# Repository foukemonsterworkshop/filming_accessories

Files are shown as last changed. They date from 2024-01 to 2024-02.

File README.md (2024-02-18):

# DIY Filming Accessories

### The Boom
I became frustrated with the limitations of tripods in my small shop space and after a few sources of inspiration started working on a balanced arm boom.
The boom is mounted to a single point, but the mount can be reused or dovetailed into a duplicated mounting point.

Projects that I felt most influenced this camera arm:
Two from Marius Hornberger  
https://www.youtube.com/watch?v=7V0NvNZmvXU
https://youtu.be/p68Y1e4acF4?si=vS-Dpx9isLgJdFHX

This massive Gantry from Inheritance Machining  
https://www.youtube.com/watch?v=t1sXvMY_vAw

And a series from The Meandrous Engineer  
https://www.youtube.com/watch?v=fble2ifR0NI

A group of .3mf files and an export of the Fusion 360 (.f3d) have been included.

### The Dolly
Real dollys are expensive, and the ones that are "smart" are much _more_ expensive.
This one is made almost entirely of 3d printed parts, extremely cheap components, and wood.

I used a knockoff arduino mega, a knockoff ILI9341 touchscreen, and some small and inexpensive stepper motors.

The necessary arduino files are {here}
And the models can be found {here}

Wiki information for the specific touch screen I used can be found  
http://www.lcdwiki.com/3.2inch_SPI_Module_ILI9341_SKU:MSP3218

I originally started with much too weak Stepper motors.  
https://www.amazon.com/gp/product/B07YRHX73L/ref=ppx_yo_dt_b_search_asin_title?ie=UTF8&psc=1

And a related tutorial I used is here:  
https://lastminuteengineers.com/28byj48-stepper-motor-arduino-tutorial/

After the initial test and finding that they would not perform the required action, I switched to these nema 17 stepper motors.  
https://www.amazon.com/dp/B00PNEQKC0?psc=1&ref=ppx_yo2ov_dt_b_product_details  
https://www.amazon.com/dp/B00PNEQ79Q?psc=1&ref=ppx_yo2ov_dt_b_product_details

L298N motor drivers  
Testing with these motor drivers resulted in jittery movement and drop in power when controlled in tandem.  
They also got super hot.  
https://www.amazon.com/dp/B00NJOTBOK?psc=1&ref=ppx_yo2ov_dt_b_product_details

And these related tutorial from the same place  
https://lastminuteengineers.com/stepper-motor-l298n-arduino-tutorial/

TB6600 stepper drivers  
I moved on to a more familiar CNC style controller  
https://www.amazon.com/gp/product/B088CRCMP7/ref=ppx_yo_dt_b_asin_title_o00_s00?ie=UTF8&th=1

And used these tutorials:  
https://www.makerguides.com/tb6600-stepper-motor-driver-arduino-tutorial/

A group of .3mf files and an export of the Fusion 360 (.f3d) have been included.
In addition some of the sub-assembly projects have been included for further customation.

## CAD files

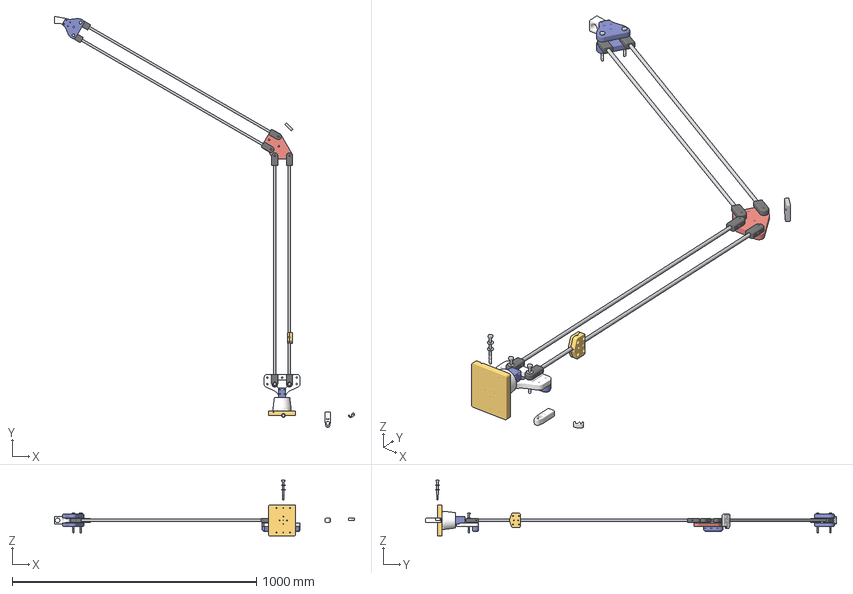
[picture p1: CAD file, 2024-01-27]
Boom3dFiles/Balanced Arm Boom v16.3mf
1229.1 x 1682.1 x 228.1 mm
Attachment Plate V2
Foot (1) x 4
Foot x 4
Link
Rod x 4
v2

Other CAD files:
Dolly3dFiles/Adjustable Phone Clamp v7.f3d
Dolly3dFiles/Parameterized Cable Chain v8.f3d

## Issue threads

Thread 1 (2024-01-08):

Navigate to Home from button

foukemonsterworkshop, 2024-01-08:
When creating a HomeButton, the NavigateTarget returns as a large number and not the intended enum

foukemonsterworkshop, 2024-01-10:
Fixed

Closed 2024-01-10.

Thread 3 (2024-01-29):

L298N Motor Driver imprecise for use case

foukemonsterworkshop, 2024-01-29:
L298N Driver should be replaced so models need to reflect this change and code will interact with the drivers differently

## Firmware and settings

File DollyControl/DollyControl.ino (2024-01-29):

#include <LCDWIKI_GUI.h>    //Core graphics library
#include <LCDWIKI_SPI.h>    //Hardware-specific library
#include <LCDWIKI_TOUCH.h>  //touch screen library

#include <Regexp.h>

#include "ScreenDefinitions.h"
#include "MenuEnums.h"

#include "StepperOperation.h"

//if the IC model is known or the modules is unreadable,you can use this constructed function
LCDWIKI_SPI lcd(MODEL, CS, CD, RST, LED);  //model,cs,dc,reset,led
LCDWIKI_TOUCH touch(TCS, TCLK, TDOUT, TDIN, TIRQ);

//navigation and interaction variables
int px, py;
boolean requires_redraw = false;

MenuState current_state;
MenuState prev_state;

STEPPER_FOCUS s_focus;
STEPPER_INPUT s_input;

String current_input = "";

//machine travel variables
boolean steppers_active = true;

// Defines the number of steps per rotation
const int stepsPerRevolution = 200;
// Creates an instance of stepper class
// Pins entered in sequence IN1-IN3-IN2-IN4 for proper step sequence

//g2t belt driven
//Belt pitch: 2mm
//No. Teeth in model pulley: 40
//mm per rotation = 80mm
Stepper gantry_stepper = Stepper(stepsPerRevolution, 2, 3, 4, 5);

//herringbone gear driven
//drive gear has 18 teeth
//camera stand gear has 36 teeth
//1 rotation = .5 camera rotation
Stepper pan_stepper = Stepper(stepsPerRevolution, 6, 7, 8, 9);

void setup(void) {
  Serial.begin(9600);
  Serial.println("");

  current_state = MAIN;
  requires_redraw = true;

  lcd.Init_LCD();
  lcd.Set_Rotation(2);
  touch.TP_Set_Rotation(3);
  touch.TP_Init(lcd.Get_Rotation(), lcd.Get_Display_Width(), lcd.Get_Display_Height());
  lcd.Fill_Screen(WHITE);

  gantry_stepper.setSpeed(60);

}

void loop(void) {

  if (requires_redraw) {
    lcd.Fill_Screen(WHITE);
    requires_redraw = false;

    init_menu(current_state);
  }

  px = 0;
  py = 0;
  touch.TP_Scan(0);
  if (touch.TP_Get_State() & TP_PRES_DOWN) {
    px = touch.x;
    py = touch.y;
  }

  interact_with_menu(current_state, px, py);

}

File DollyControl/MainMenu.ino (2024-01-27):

void init_main_menu() {
  int x = 5;
  int y = 5;
  int x1 = lcd.Get_Display_Width() - x;
  int y1 = 30;

  int list_position = 0;
  int display_position = 1;

  int labelXOffset = 2 * x;
  int labelYOffset = 12;

  String content = steppers_active ? "Motors Active" : "Motors Inactive";
  int label_size = 2;

  char* labels[6] = { " ", "Home Machine", "Jog Machine", "Pan Machine", "Truck Machine", "Parallax Machine" };

  for (int i = 0; i < 6; i++) {
    int16_t color;
    if (i == 0) {
      color = steppers_active ? GREEN : RED;
    } else {
      color = LIGHTGREY;
      content = labels[i];
    }

    lcd.Set_Draw_color(color);
    lcd.Fill_Round_Rectangle(
      x,
      (display_position * y) + (list_position * y1),
      x1,
      display_position * (y + y1),
      3);

    show_label(content, labelXOffset, labelYOffset + (i * (y1 + y)), label_size, BLACK, BLACK, 1);

    list_position++;
    display_position++;
  }
}

void interact_main_menu(int px, int py) {
  int x = 5;
  int y = 5;
  int x1 = lcd.Get_Display_Width() - x;
  int y1 = 30;

  int list_position = 0;
  int display_position = 1;

  int labelXOffset = 2 * x;
  int labelYOffset = 12;

  if (is_pressed(px, py,
                 x,
                 (display_position * y) + (list_position * y1),
                 x1,
                 display_position * (y + y1))) {
    steppers_active = !steppers_active;
    lcd.Set_Draw_color(steppers_active ? GREEN : RED);
    lcd.Fill_Round_Rectangle(
      x,
      (display_position * y) + (list_position * y1),
      x1,
      display_position * (y + y1),
      3);
    show_label(steppers_active ? "Motors Active" : "Motors Inactive", labelXOffset, labelYOffset, 2, BLACK, BLACK, 1);
    delay(1000);
  }

  list_position++;
  display_position++;

  MenuState state[6] = { MAIN, HOME, JOG, PAN, TRUCK, PARALLAX };

  for (int i = 1; i < 6; i++) {

    if (is_pressed(px, py,
                   x,
                   (display_position * y) + (list_position * y1),
                   x1,
                   display_position * (y + y1))) {
      button_reaction(
        DARKGREY,
        x,
        (display_position * y) + (list_position * y1),
        x1,
        display_position * (y + y1));

      requires_redraw = true;
      prev_state = current_state;
      current_state = state[i];
      delay(150);
    }

    list_position++;
    display_position++;
  }

}

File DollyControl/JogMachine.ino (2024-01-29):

void init_jog_menu() {
  int x = 5;
  int y = 5;
  int x1 = lcd.Get_Display_Width() - x;
  int y1 = 30;

  int list_position = 0;
  int display_position = 1;

  int labelXOffset = 2 * x;
  int labelYOffset = 12;

  lcd.Set_Draw_color(DARKGREY);
  lcd.Fill_Round_Rectangle(
    x,
    (display_position * y) + (list_position * y1),
    x1,
    display_position * (y + y1),
    3);
  show_label("Jog Machine", labelXOffset, labelYOffset, 2, BLACK, BLACK, 1);

  lcd.Set_Draw_color(GREEN);
  float jogX = lcd.Get_Width() / 4;
  float jogY = lcd.Get_Height() / 4;
  lcd.Fill_Circle(jogX, jogY, 25);

  String label_text = "Left";

  float label_size = 2.0;
  show_label(label_text,
             jogX - label_text.length() * label_size * 6 / 2 + label_size / 2 + 1,
             jogY - label_size * 8 / 2 + label_size / 2 + 1,
             label_size,
             BLACK, BLACK, 1);

  jogX = lcd.Get_Width() * (3.0 / 4.0);

  lcd.Fill_Circle(jogX, jogY, 25);

  label_text = "Right";

  show_label(label_text,
             jogX - label_text.length() * label_size * 6 / 2 + label_size / 2 + 1,
             jogY - label_size * 8 / 2 + label_size / 2 + 1,
             label_size,
             BLACK, BLACK, 1);

  jogY = lcd.Get_Height() / 2;
  jogX = lcd.Get_Width() / 4;

  lcd.Fill_Circle(jogX, jogY, 25);

  label_text = "P Left";

  show_label(label_text,
             jogX - label_text.length() * label_size * 6 / 2 + label_size / 2 + 1,
             jogY - label_size * 8 / 2 + label_size / 2 + 1,
             label_size,
             BLACK, BLACK, 1);

  jogX = lcd.Get_Width() * (3.0/ 4.0);

  lcd.Fill_Circle(jogX, jogY, 25);

  label_text = "P Right";

  show_label(label_text,
             jogX - label_text.length() * label_size * 6 / 2 + label_size / 2 + 1,
             jogY - label_size * 8 / 2 + label_size / 2 + 1,
             label_size,
             BLACK, BLACK, 1);

  draw_nav_button("Home");
}

void interact_jog_menu(int px, int py) {

  /*
    Serial.print("Jog Menu click-> x: ");
    Serial.print(px);
    Serial.print(" y: ");
    Serial.println(py);
  */

  float label_size = 2.0;

  check_home_button(px, py);

  float jogX = lcd.Get_Width() / 4;
  float jogY = lcd.Get_Height() / 4;

  gantry_stepper.setSpeed(30);
  pan_stepper.setSpeed(15);

  if (is_pressed(px, py, jogX - 25, jogY - 25, jogX + 25, jogY + 25)) {
    interact_button(200, jogX, jogY, 25, GREEN, DARKGREEN, label_size, "LEFT");
    Serial.println("Left Click");

    gantry_stepper.step(-200);

    Serial.println("Finished stepping");
  }

  jogX = lcd.Get_Width() * (3.0 / 4.0);
  if (is_pressed(px, py, jogX - 25, jogY - 25, jogX + 25, jogY + 25)) {
    interact_button(200, jogX, jogY, 25, GREEN, DARKGREEN, 2, "RIGHT");
    Serial.println("Right Click");

    gantry_stepper.step(200);
    Serial.println("Finished stepping");
  }
  
  jogX = lcd.Get_Width() / 4;
  jogY = lcd.Get_Height() / 2;

  if (is_pressed(px, py, jogX - 25, jogY - 25, jogX + 25, jogY + 25)) {
    interact_button(200, jogX, jogY, 25, GREEN, DARKGREEN, 2, "P LEFT");
    Serial.println("P Left Click");

    pan_stepper.step(-200);
    Serial.println("Finished stepping");
  }

  jogX = lcd.Get_Width() * (3.0 / 4.0);
  
  if (is_pressed(px, py, jogX - 25, jogY - 25, jogX + 25, jogY + 25)) {
    interact_button(200, jogX, jogY, 25, GREEN, DARKGREEN, 2, "P RIGHT");
    Serial.println("P Right Click");

    pan_stepper.step(200);
    Serial.println("Finished stepping");
  }
}

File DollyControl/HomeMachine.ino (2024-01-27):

void init_home_machine_menu() {
  int x = 5;
  int y = 5;
  int x1 = lcd.Get_Display_Width() - x;
  int y1 = 30;

  int list_position = 0;
  int display_position = 1;

  int labelXOffset = 2 * x;
  int labelYOffset = 12;

  for (int i = 0; i < 2; i++) {
    lcd.Set_Draw_color(LIGHTGREY);
    lcd.Fill_Round_Rectangle(
      x,
      (display_position * y) + (list_position * y1),
      x1,
      display_position * (y + y1),
      3);

    list_position++;
    display_position++;
  }

  show_label("Main From Home", labelXOffset, labelYOffset, 2, BLACK, BLACK, 1);

  show_label("Data Input Testing", labelXOffset, labelYOffset + (y1 + y), 2, BLACK, BLACK, 1);

  draw_nav_button("Home");
}

void interact_home_machine_menu(int px, int py) {
  int x = 5;
  int y = 5;
  int x1 = lcd.Get_Display_Width() - x;
  int y1 = 30;

  int list_position = 0;
  int display_position = 1;

  int labelXOffset = 2 * x;
  int labelYOffset = 12;

  check_home_button(px, py);

  if (is_pressed(px, py,
                 x,
                 (display_position * y) + (list_position * y1),
                 x1,
                 display_position * (y + y1))) {
    requires_redraw = true;
    current_state = MAIN;
    delay(150);
  }

  list_position++;
  display_position++;

  if (is_pressed(px, py,
                 x,
                 (display_position * y) + (list_position * y1),
                 x1,
                 display_position * (y + y1))) {
    requires_redraw = true;
    prev_state = current_state;
    current_state = VALUE_ENTRY;
    delay(150);
  }
}

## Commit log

2024-01-06 initial arduino code
2024-01-07 abandoning preset buttons
2024-01-08 button purpose enum
2024-01-08 home button added, navigation target issue
    [DollyControl.ino, MenuDisplay.ino]
2024-01-10 reorg label to button
2024-01-10 button drawing updates
2024-01-11 smaller memory footprint, faster drawing
2024-01-27 updating and adding 3d and fusion files
    [Adjustable Phone Clamp v7.f3d, Balanced Arm Boom v16.3mf, Parameterized Cable Chain v8.f3d]
